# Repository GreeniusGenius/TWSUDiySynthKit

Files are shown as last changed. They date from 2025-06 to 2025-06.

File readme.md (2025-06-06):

# About

- This product is borne out of an original synthesiser kit built by the now bankrupt [Tech Will Save Us](https://en.wikipedia.org/wiki/Technology_Will_Save_Us) company.
- The solderless breadboard nature of it frustrated me, and the lack of room to add a microcontroller for MIDI functionality on the breadboard made it unusable for how I would wish to use it.
- Then I got bored whilst designing it, and decided I'd turn it into a Pi Pico (2(W)) dev board too.
- That way I can prototype all of my projects in a single multipurpose board.
- It supports a Raspberry Pi standard hat.
- It supports a Raspberry Pi Pico bonnet.
- _The second Pi you see in the renderings is actually where two headers will go allowing bonnets to be attached like eInk displays_
- It supports Adafruit Stemma QT and Stemma connectors - which are perfect for prototyping using breakout boards due to the reliable solderless connections.
- It lets me try out the usage of jumpers to bypass voltage dividers reducing potential PCB revisions required due to calculation errors.
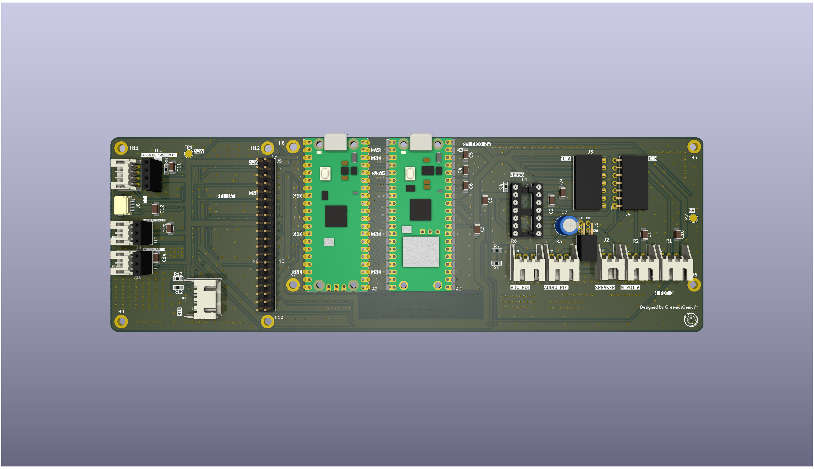
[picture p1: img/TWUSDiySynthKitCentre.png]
Centred Image

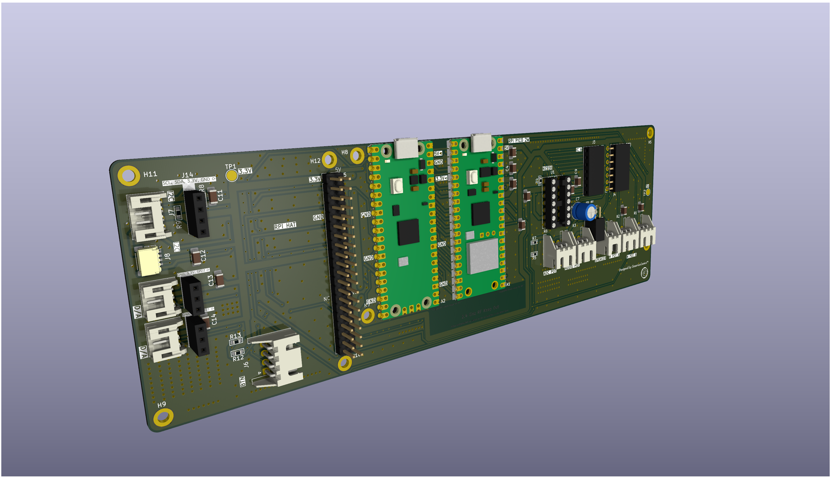
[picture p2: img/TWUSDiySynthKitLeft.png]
Left Hand Image

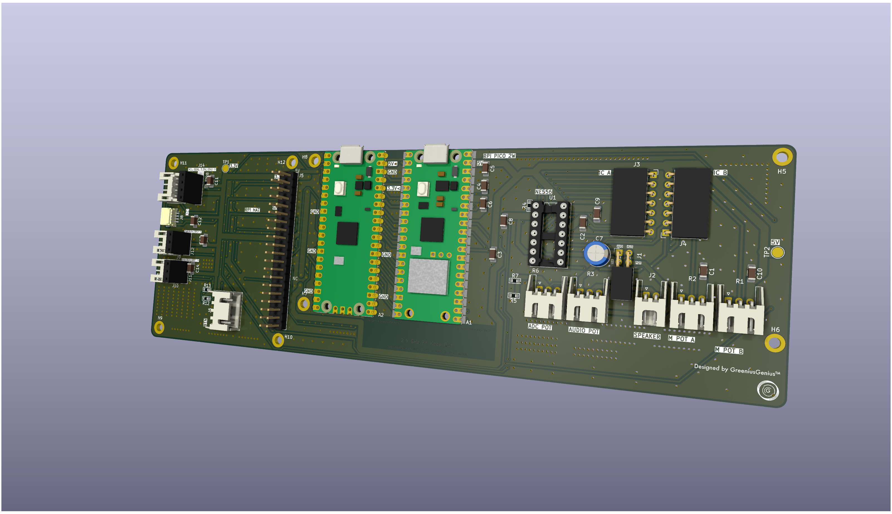
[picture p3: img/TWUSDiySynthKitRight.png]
Right Hand Image

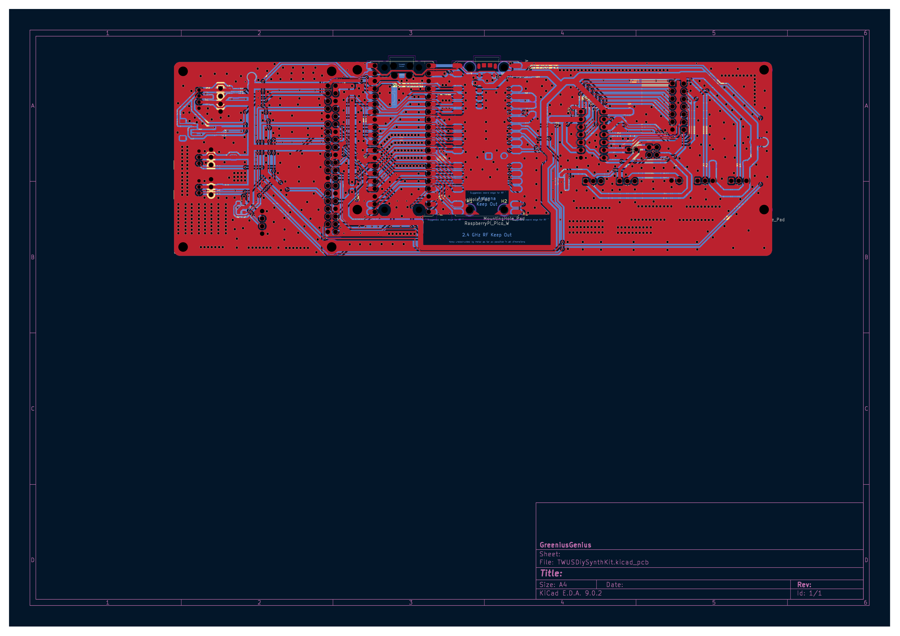
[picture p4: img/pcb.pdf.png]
PCB View

_The PCB is a cost-effective two layer design with ground pours and high density of via stitching reduce ground loops and EMI._
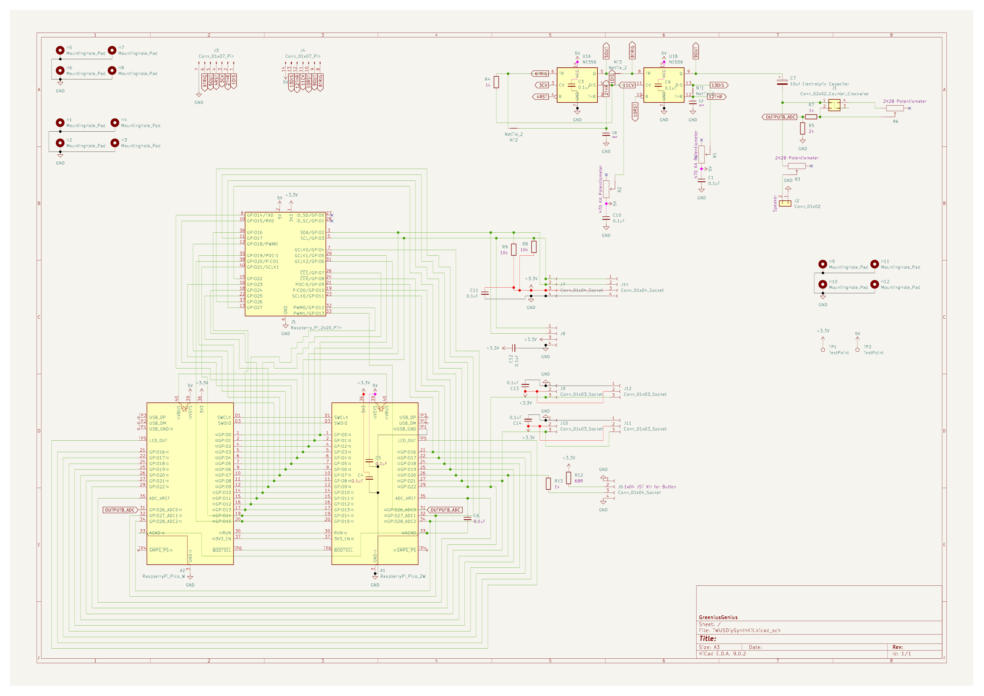
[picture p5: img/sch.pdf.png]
Schematic View

_Plated and grounded mounting holes are used to allow easy multimeter probing and increase durability._
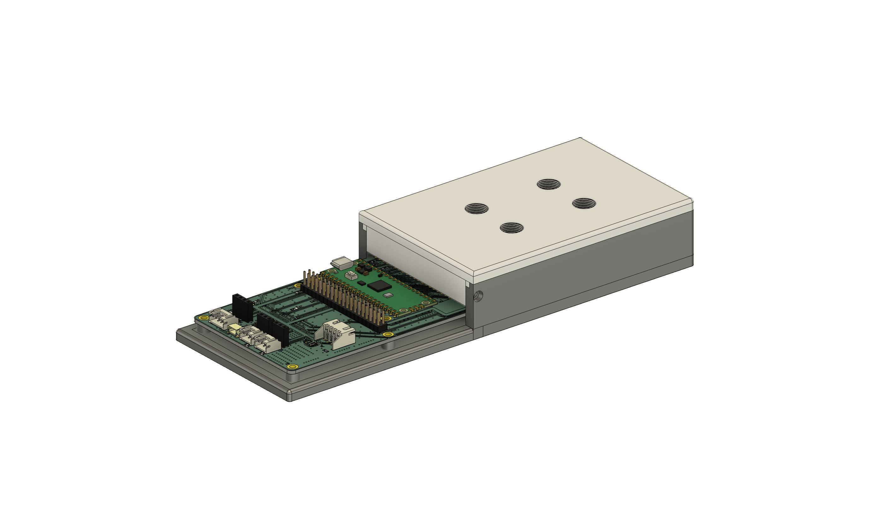
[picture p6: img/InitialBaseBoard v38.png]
Case View

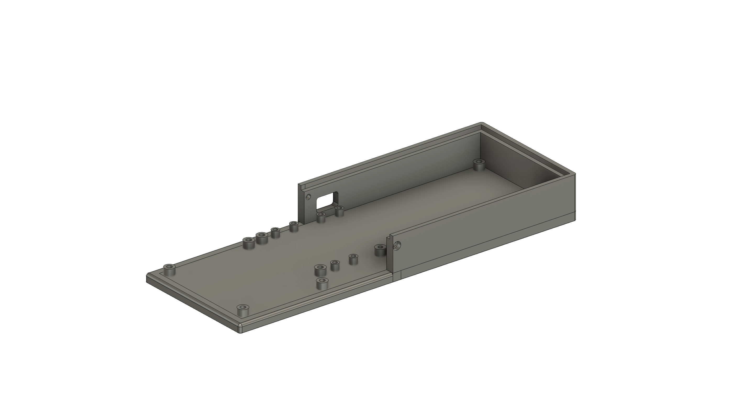
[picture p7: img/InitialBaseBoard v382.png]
Case View No Lid

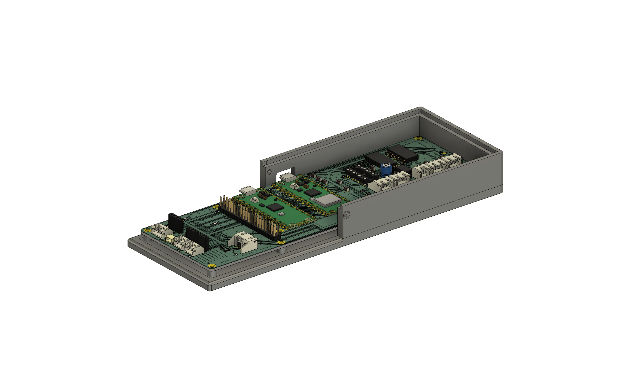
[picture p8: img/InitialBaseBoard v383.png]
Case View No PCB

_The case shields the synthesiser board and Pi Pico (2(W)) whilst the bonnet, hat, and JST connectors for peripherals are easily accessible_

## Bill of Materials
| Reference | Qty | Value | Datasheet | Link / URL | Manufacturer  | Manufacturer_Part_Number | Price (GBP) | GBP/USD | Price (USD) | Justification |
| --- | --- | --- | --- | --- | --- | --- | --- | --- | --- | --- |
| R1, R2 | 2 | 2k 16mm Potentiometer | [https://static.rapidonline.com/pdf/65-1480.pdf](https://static.rapidonline.com/pdf/65-1480.pdf) | https://www.rapidonline.com/omeg-eco2k2lin-2k2-linear-single-16mm-control-pot-65-1401 | Omeg | ECO2K2LIN | £1.75 |  $              1.36 | USD 2.38 | For the volume control and adjustment of the midi volume too |
| R3, R6 | 2 | 470k 16mm potentiometer | [https://static.rapidonline.com/pdf/65-1400e.pdf](https://static.rapidonline.com/pdf/65-1400e.pdf) | https://www.rapidonline.com/omeg-ecoswx470klin-470k-eco-16mm-linear-switched-control-65-1494 | Omeg | ECOSWX470KLIN | £2.57 |  $              1.36 | USD 3.49 | For the input for the synthesizer |
| J6 | 1 | JST XH p2.54mm 4 pin 20cm long wire and connector | [https://www.aliexpress.com/item/1005007460897865.html#nav-specification](https://www.aliexpress.com/item/1005007460897865.html#nav-specification) | [https://www.aliexpress.com/item/1005007460897865.html](https://www.aliexpress.com/item/1005007460897865.html) | Generic | ~ | £0.75 |  $              1.36 | USD 1.02 | Cables for the PCB mount JST connectors to attach accessories |
| J8 | 1 |  JST SH 1.0mm 4 pin 300mm wire and conenctor | https://www.aliexpress.com/item/1005007218127653.html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 | https://www.aliexpress.com/item/1005007218127653.html | Generic | ~ | £0.81 |  $              1.36 | USD 2.21 | |
| J7 | 1 | JST PH 2.0mm 4 pin connector | https://www.aliexpress.com/item/32959854422.html#nav-description | https://www.aliexpress.com/item/32959854422.html | Generic | ~ | £1.63 |  $              1.36 | USD 1.91 | |
| J8 | 2 | JST PH 2.0mm 3 pin connector | https://www.aliexpress.com/item/32959854422.html#nav-description | https://www.aliexpress.com/item/32959854422.html | Generic | ~ | £1.41 |  $              1.36 | USD 1.91 | |
| J2 | 1 | JST XH p2.54mm 2 pin 20cm long wire and connector | [https://www.aliexpress.com/item/1005007460897865.html#nav-specification](https://www.aliexpress.com/item/1005007460897865.html#nav-specification) | [https://www.aliexpress.com/item/1005007460897865.html](https://www.aliexpress.com/item/1005007460897865.html) | Generic | ~ | £0.75 |  $              1.36 | USD 1.02 | |
| J6 | 1 | 16mm 3V LED Button | [https://www.aliexpress.com/item/1005008024309525.html#nav-specification](https://www.aliexpress.com/item/1005008024309525.html#nav-specification) | https://www.aliexpress.com/item/1005008024309525.html | Generic | ~ | £1.26 |  $              1.36 | USD 1.71 | Push to pair bluetooth |
| | | USB-A to Micro-USB cable 0.9m | https://www.amazon.co.uk/dp/B0711PVX6Z?th=1 | https://www.amazon.co.uk/dp/B0711PVX6Z | Amazon Basics | ~ | £3.16 |  $              1.36 | USD 4.29 | Genuinely run out of Micro USB cables - happy to find a cheaper one if necessary as long as it does data |
| PCB | 1 | 5 PCBs (minimum JLCPCB order) | ~ | jlcpcb.com | JLCPCB | ~ | £23.35 |  $              1.36 | USD 31.71 | The PCB |
| | | | | | | | | | | |
| | | | | | | | | | | |
| | | | | | | | | | | |
| | | | | | | Total Price | £37.44 | | USD 51.65 | |
| **Reference** | **Qty** | **Value** | **DNP** | **Exclude from BOM** | **Exclude from Board** | **Footprint** | **Datasheet** | **JLCPCB ID** | **Manufacturer** | **Manufacturer_Part_Number** | **Mouser Part Number** |
| -------------------------------- | ------- | ---------------------------- | ------- | -------------------- | ---------------------- | ---------------------------------------------------------------- | ------------------------------------------------------------------------------------------------------------------------------------------------------------------------------------------------------------------------------------------------------------------------------ | ------------- | ------------------------------------- | ---------------------------- | ---------------------- |
| **R5** | 1 | 2k_0603 | | | | PCM_Resistor_SMD_AKL:R_0603_1608Metric_Pad0.98x0.95mm_HandSolder | [https://www.vishay.com/doc?60018](https://www.vishay.com/doc?60018) | C2076992 | Vishay | M55342E12B2B00RT5 | 75-M55342E12B2B00RT5 |
| **R8,R9** | 2 | 10k_0603 | | | | PCM_Resistor_SMD_AKL:R_0603_1608Metric_Pad0.98x0.95mm_HandSolder | [https://www.vishay.com/doc?28758](https://www.vishay.com/doc?28758) | C2130614 | Vishay | TNPW060310K0FHEA | 71-TNPW060310K0FHEA |
| **R4,R7** | 2 | 1k_0603 | | | | PCM_Resistor_SMD_AKL:R_0603_1608Metric_Pad1.05x0.95mm_HandSolder | [https://www.mouser.co.uk/datasheet/2/385/SEI_RMCF_RMCP-3077565.pdf](https://www.mouser.co.uk/datasheet/2/385/SEI_RMCF_RMCP-3077565.pdf) | C4130738 | SEI Stackpole | RMCF0603JG1K00 | 708-RMCF0603JG1K00 |
| **R13** | 1 | 1k_1210 | | | | PCM_Resistor_SMD_AKL:R_0603_1608Metric_Pad1.05x0.95mm_HandSolder | [https://4donline.ihs.com/images/VipMasterIC/IC/PANA/PANA-S-A0012789169/PANA-S-A0012789169-1.pdf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](https://4donline.ihs.com/images/VipMasterIC/IC/PANA/PANA-S-A0012789169/PANA-S-A0012789169-1.pdf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) | C20024203 | Yageo | ERJ-T14LK102U | 667-ERJ-T14LK102U |
| **C7** | 1 | 10uf Electrolytic Capacitor  | | | | PCM_Capacitor_THT_AKL:CP_Radial_D6.3mm_P2.50mm | [https://industrial.panasonic.com/cdbs/www-data/pdf/RDF0000/ABA0000C1059.pdf](https://industrial.panasonic.com/cdbs/www-data/pdf/RDF0000/ABA0000C1059.pdf) | C1583769 | Panasonic | ECE-A1HKS100B | 667-ECE-A1HKS100B |
| **R12** | 1 | 68R_1210 | | | | PCM_Resistor_SMD_AKL:R_0603_1608Metric_Pad1.05x0.95mm_HandSolder | [https://www.mouser.co.uk/datasheet/2/447/PYu_AC_51_RoHS_L_11-3418659.pdf](https://www.mouser.co.uk/datasheet/2/447/PYu_AC_51_RoHS_L_11-3418659.pdf) | C230487 | Yageo | AC1210JR-0768RL | 603-AC1210JR-0768RL |
| **U1** | 1 | NE556 | | | | Package_DIP:DIP-14_W7.62mm_Socket_LongPads | [http://www.ti.com/lit/ds/symlink/ne556.pdf](http://www.ti.com/lit/ds/symlink/ne556.pdf) | C66175 | Texas Instruments | NE556N | 595-NE556N |
| **A1** | 1 | RaspberryPi_Pico_2W | | | | Module_RaspberryPi_Pico:RaspberryPi_Pico_W_SMD | [https://datasheets.raspberrypi.com/picow/pico-2-w-datasheet.pdf](https://datasheets.raspberrypi.com/picow/pico-2-w-datasheet.pdf) | | Raspberry Pi Foundation | SC1633 | 358-SC1633 |
| **J8** | 1 | Conn_01x04_Socket | | | | Connector_JST:JST_SH_SM04B-SRSS-TB_1x04-1MP_P1.00mm_Horizontal | [https://www.mouser.co.uk/datasheet/2/564/eGH-3477624.pdf](https://www.mouser.co.uk/datasheet/2/564/eGH-3477624.pdf) | C7279904 | Japan Solderless Terminals | SM04B-GHMG-TB-(LF)(SN) | 306-SM04BGHMGTBLFSN |
| **J6** | 1 | Conn_01x04_Socket | | | | Connector_JST:JST_XH_S4B-XH-A-1_1x04_P2.50mm_Horizontal | [https://www.mouser.co.uk/datasheet/2/564/eXH-3476786.pdf](https://www.mouser.co.uk/datasheet/2/564/eXH-3476786.pdf) | C163037 | Japan Solderless Terminals | S4B-XH-A-1(LF)(SN) | 306-S4BXHA1LFSN |
| **R3,R6** | 2 | ECO2K2LIN | | | | Connector_JST:JST_XH_S3B-XH-A-1_1x03_P2.50mm_Horizontal | [https://static.rapidonline.com/pdf/65-1400e.pdf](https://static.rapidonline.com/pdf/65-1400e.pdf), [https://www.mouser.co.uk/datasheet/2/564/eXH-3476786.pdf](https://www.mouser.co.uk/datasheet/2/564/eXH-3476786.pdf) | C163036 | Japan Solderless Terminals | S3B-XH-A-1(LF)(SN) | 306-S3BXHA1LFSN |
| **R1,R2** | 2 | ECOSWX470KLIN | | | | Connector_JST:JST_XH_S3B-XH-A-1_1x03_P2.50mm_Horizontal | [https://static.rapidonline.com/pdf/65-1494.pdf](https://static.rapidonline.com/pdf/65-1494.pdf), [https://www.mouser.co.uk/datasheet/2/564/eXH-3476786.pdf](https://www.mouser.co.uk/datasheet/2/564/eXH-3476786.pdf) | C163036 | Japan Solderless Terminals | S3B-XH-A-1(LF)(SN) | 306-S3BXHA1LFSN |
| **J7** | 1 | Conn_01x04_Socket | | | | Connector_JST:JST_PH_S4B-PH-K_1x04_P2.00mm_Horizontal | [https://www.mouser.co.uk/datasheet/2/564/JST_B4B_PH_SM4_TB_LF_SN_ePH-3481264.pdf](https://www.mouser.co.uk/datasheet/2/564/JST_B4B_PH_SM4_TB_LF_SN_ePH-3481264.pdf) | C157926 | Japan Solderless Terminals | S4B-PH-K-S(LF)(SN) | 306-S4BPHKSLFSN |
| **J9,J10** | 2 | Conn_01x03_Socket | | | | Connector_JST:JST_PH_S3B-PH-K_1x03_P2.00mm_Horizontal | [https://www.mouser.co.uk/datasheet/2/564/JST_B4B_PH_SM4_TB_LF_SN_ePH-3481264.pdf](https://www.mouser.co.uk/datasheet/2/564/JST_B4B_PH_SM4_TB_LF_SN_ePH-3481264.pdf) | C157929 | Japan Solderless Terminals Commercial | S3B-PH-K-S(LF)(SN) | 306-S3BPHKSLFSN |
| **J2** | 1 | Conn_01x02 | | | | Connector_JST:JST_XH_S2B-XH-A-1_1x02_P2.50mm_Horizontal | [https://www.mouser.co.uk/datasheet/2/564/eXH-3476786.pdf](https://www.mouser.co.uk/datasheet/2/564/eXH-3476786.pdf) | C157931 | Japan Solderless Terminals | S2B-XH-A(LF)(SN) | 306-S2B-XH-ALFSN |
| **C4,C5,C6** | 3 | 0.1uF_0603_16V | | | | Capacitor_SMD:C_1206_3216Metric_Pad1.33x1.80mm_HandSolder | [https://www.mouser.co.uk/datasheet/2/585/MLCC-1837944.pdf](https://www.mouser.co.uk/datasheet/2/585/MLCC-1837944.pdf) | C6766062 | Samsung Electro-Mechanics | CL31B104KBCNNND | 187-CL31B104KBCNNND |
| **C1,C3,C9,C10,C11,C12,C13,C14** | 8 | 0.1uF | | | | Capacitor_SMD:C_1206_3216Metric_Pad1.33x1.80mm_HandSolder | [https://www.mouser.co.uk/datasheet/2/585/MLCC-1837944.pdf](https://www.mouser.co.uk/datasheet/2/585/MLCC-1837944.pdf) | C6766062 | Samsung Electro-Mechanics | CL31B104KBCNNND | 187-CL31B104KBCNNND |
| **C2,C8** | 2 | 10nF_0603_25V | | | | Capacitor_SMD:C_1206_3216Metric_Pad1.33x1.80mm_HandSolder | [https://www.mouser.co.uk/datasheet/2/585/MLCC-1837944.pdf](https://www.mouser.co.uk/datasheet/2/585/MLCC-1837944.pdf) | C16196152 | Samsung Electro-Mechanics | CL31B103KHFNFNE | 187-CL31B103KHFNFNE |
| **TP1,TP2** | 2 | TestPoint | | | | TestPoint:TestPoint_Pad_D2.5mm | ~ | | | | |
| **NT1,NT2,NT3** | 3 | NetTie_2 | | Excluded from BOM | | NetTie:NetTie-2_SMD_Pad0.5mm | ~ | | | | |
| **J14** | 1 | Conn_01x04_Socket | | | | Connector_PinSocket_2.54mm:PinSocket_1x04_P2.54mm_Vertical | ~ | | | | |
| **J11,J12** | 2 | Conn_01x03_Socket | | | | Connector_PinSocket_2.54mm:PinSocket_1x03_P2.54mm_Vertical | ~ | | | | |
| **J5** | 1 | Raspberry_Pi_2x20_PTH | | | | Connector_PinHeader_2.54mm:PinHeader_2x20_P2.54mm_Vertical | [https://www.raspberrypi.org/documentation/hardware/raspberrypi/schematics/rpi_SCH_3bplus_1p0_reduced.pdf](https://www.raspberrypi.org/documentation/hardware/raspberrypi/schematics/rpi_SCH_3bplus_1p0_reduced.pdf) | | | | |
| **J3,J4** | 2 | Conn_01x07_Pin | | | | Connector_PinSocket_2.54mm:PinSocket_1x07_P2.54mm_Horizontal | ~ | | | | |
| **J1** | 1 | Conn_02x02_Counter_Clockwise | | | | Connector_PinSocket_2.54mm:PinSocket_2x02_P2.54mm_Horizontal | ~ | | | | |
| **H5,H6,H7,H8,H9,H10,H11,H12** | 8 | MountingHole_Pad | | Excluded from BOM | | MountingHole:MountingHole_2.7mm_M2.5_DIN965_Pad | ~ | | | | |
| **H1,H2,H3,H4** | 4 | MountingHole_Pad | | Excluded from BOM | | MountingHole:MountingHole_2.2mm_M2_DIN965 | ~ | | | | |
| **A2** | 1 | RaspberryPi_Pico_W | | Excluded from BOM | | Module_RaspberryPi_Pico:RaspberryPi_Pico_Common_MountingHoles | [https://datasheets.raspberrypi.com/picow/pico-w-datasheet.pdf](https://datasheets.raspberrypi.com/picow/pico-w-datasheet.pdf) | | | | |

| FileName | Quantity | Price  |
|---|---|---|
| InitialBaseBoard Base.step | 1 | $17.16 |
| InitialBaseBoard Lid.step  | 1 | $7.78  |

Notes: The .csv file contains the PCB mounted bill of materials.
The ExtraBOM contains the wiring needed to connect etc.
The link to the mouser basket is here: https://www.mouser.co.uk/ProjectManager/ProjectDetail.aspx?AccessID=711d47ef2e

Mouser components + shipping to United Kingdom is £24.41 or US$33.12

Components in .xlsx are £43.17 or US$59.46

3D Printed Casing is about US$24.94 (£18.41) + at least US$16.10 (£11.88) shipping from PCBWay for a total of £30.29 and US$41.04

**Therefore the total cost is £97.87 and US$133.62.**

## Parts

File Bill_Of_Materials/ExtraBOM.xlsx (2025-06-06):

Reference | Qty | Value | Datasheet | Link / URL | Manufacturer | Manufacturer_Part_Number | Unit Price (GBP) | #VALUE! | Unit Price (USD) | Quantity Price (GBP) | Quantity Price (USD) | Justification
R1, R2 | 2 | 2k 16mm Potentiometer | https://static.rapidonline.com/pdf/65-1480.pdf | https://www.rapidonline.com/omeg-eco2k2lin-2k2-linear-single-16mm-control-pot-65-1401 | Omeg | ECO2K2LIN | £1.75 | $1.36 | USD 2.38 | £3.50 | USD 4.75 | For the volume control and adjustment of the midi volume too
R3, R6 | 2 | 470k 16mm potentiometer | https://static.rapidonline.com/pdf/65-1400e.pdf | https://www.rapidonline.com/omeg-ecoswx470klin-470k-eco-16mm-linear-switched-control-65-1494 | Omeg | ECOSWX470KLIN | £2.57 | $1.36 | USD 3.49 | £5.14 | USD 6.98 | For the input for the synthesizer
J6 | 1 | JST XH p2.54mm 4 pin 20cm long wire and connector | https://www.aliexpress.com/item/1005007460897865.html#nav-specification | https://www.aliexpress.com/item/1005007460897865.html | Generic | ~ | £0.75 | $1.36 | USD 1.02 | £0.75 | USD 1.02 | Cables for the PCB mount JST connectors to attach accessories
J8 | 1 | JST SH 1.0mm 4 pin 300mm wire and conenctor | https://www.aliexpress.com/item/1005007218127653.html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 | https://www.aliexpress.com/item/1005007218127653.html | Generic | ~ | £0.81 | $1.36 | USD 2.21 | £0.81 | USD 2.21
J7 | 1 | JST PH 2.0mm 4 pin connector | https://www.aliexpress.com/item/32959854422.html#nav-description | https://www.aliexpress.com/item/32959854422.html | Generic | ~ | £1.63 | $1.36 | USD 1.92 | £1.63 | USD 1.92
J8 | 2 | JST PH 2.0mm 3 pin connector | https://www.aliexpress.com/item/32959854422.html#nav-description | https://www.aliexpress.com/item/32959854422.html | Generic | ~ | £1.41 | $1.36 | USD 1.92 | £2.82 | USD 3.83
J2 | 1 | JST XH p2.54mm 2 pin 20cm long wire and connector | https://www.aliexpress.com/item/1005007460897865.html#nav-specification | https://www.aliexpress.com/item/1005007460897865.html | Generic | ~ | £0.75 | $1.36 | USD 1.02 | £0.75 | USD 1.02
J6 | 1 | 16mm 3V LED Button | https://www.aliexpress.com/item/1005008024309525.html#nav-specification | https://www.aliexpress.com/item/1005008024309525.html | Generic | ~ | £1.26 | $1.36 | USD 1.71 | £1.26 | USD 1.71 | Push to pair bluetooth
USB | 1 | USB-A to Micro-USB cable 0.9m | https://www.amazon.co.uk/dp/B0711PVX6Z?th=1 | https://www.amazon.co.uk/dp/B0711PVX6Z | Amazon Basics | ~ | £3.16 | $1.36 | USD 4.29 | £3.16 | USD 4.29 | Genuinely run out of Micro USB cables - happy to find a cheaper one if necessary as long as it does data
PCB | 1 | 5 PCBs (minimum JLCPCB order) | ~ | jlcpcb.com | JLCPCB | ~ | £23.35 | $1.36 | USD 31.72 | £23.35 | USD 31.72 | The PCB
 |  |  |  |  |  |  |  |  |  | GBP | USD
 |  |  |  |  |  |  |  |  | Total | £43.17 | USD 59.46

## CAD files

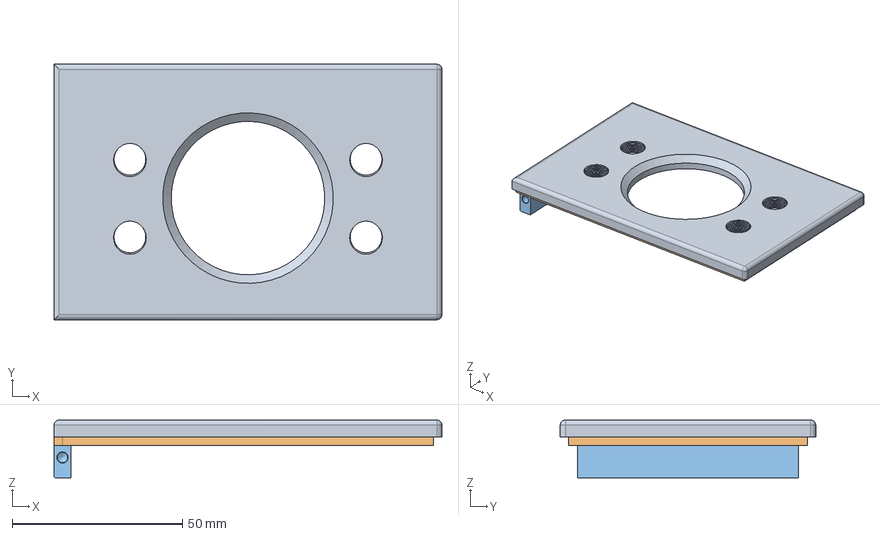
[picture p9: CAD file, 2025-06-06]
cad/InitialBaseBoard Lid.step
113.8 x 75.0 x 17.0 mm
LidTop
LidKey
LidSideWall

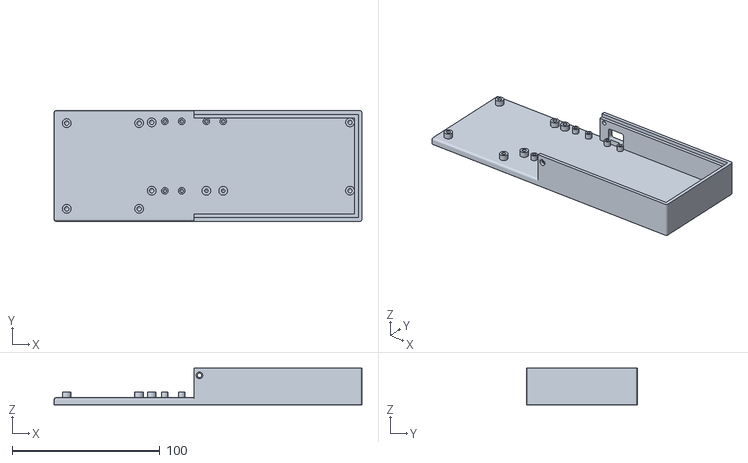
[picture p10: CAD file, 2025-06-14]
cad/sat14jun/InitialBaseBoard v63 Base.stl
208.4 x 75.0 x 25.0

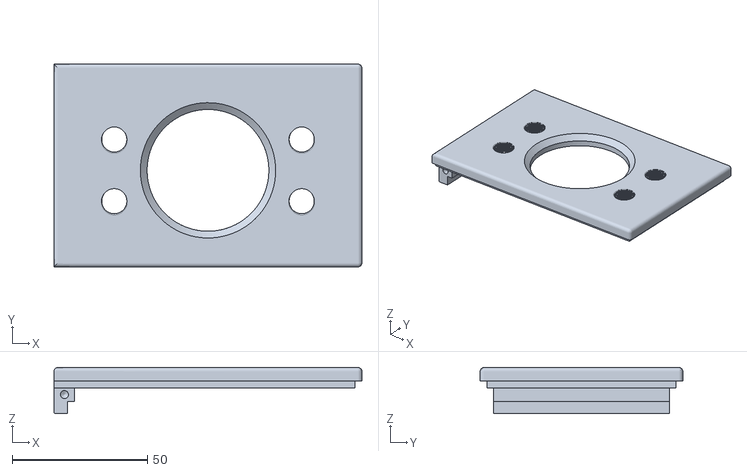
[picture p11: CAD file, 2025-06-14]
cad/sat14jun/InitialBaseBoard v63 Lid.stl
113.8 x 75.0 x 17.0

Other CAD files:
cad/InitialBaseBoard Base.step
cad/InitialBaseBoard Base.stl
cad/InitialBaseBoard Lid.stl

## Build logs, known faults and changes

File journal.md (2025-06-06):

# Journal
 - Oldest at top, newest at bottom of text file.

## Thu 5 Jun 2025
I'd love to say I knew how long I spent on the project so far.
The answer is I don't know.
Probably at least 6 hours, beginning on 31st of May 2025.
I took some inspiration from [baklokb/pcb-pico-pi-base](https://github.com/bablokb/pcb-pico-pi-base)
This allowed me to connect the Pico with standard Pi hats.
PCB View
_By now the PCB was pretty much complete_

## Fri 6 Jun 2025
Spent a few hours working on CAD for the casing:
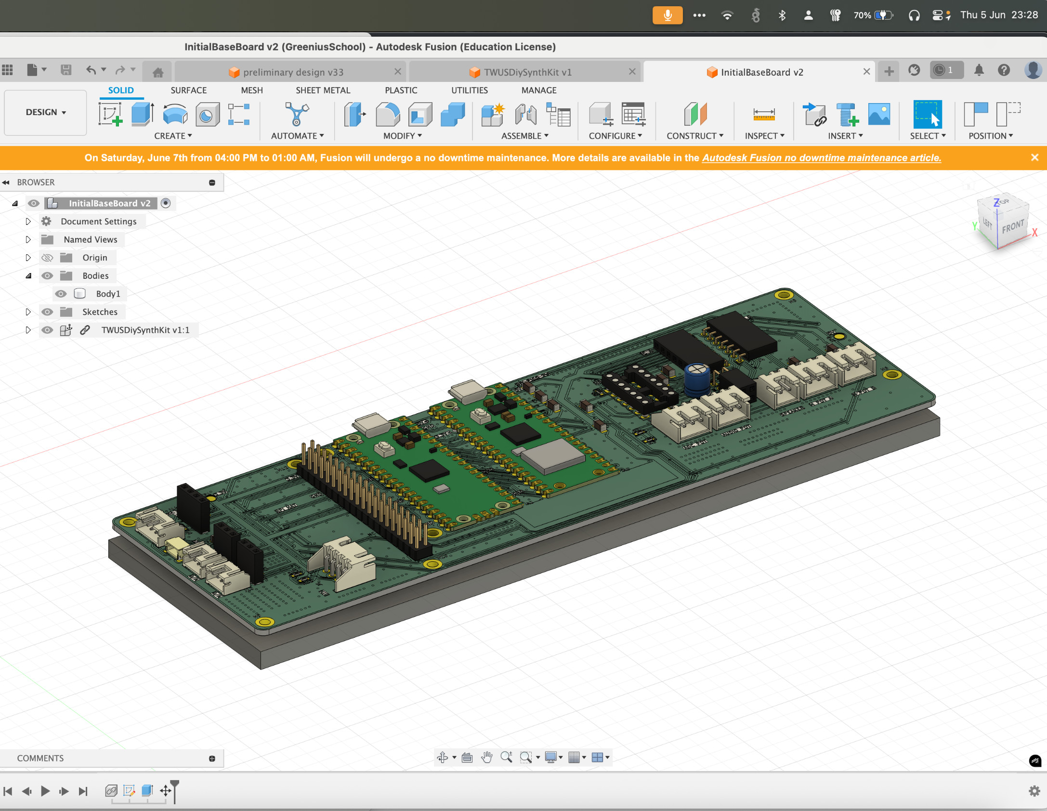
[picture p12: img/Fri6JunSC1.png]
Base Plate

_Started with a base plate_

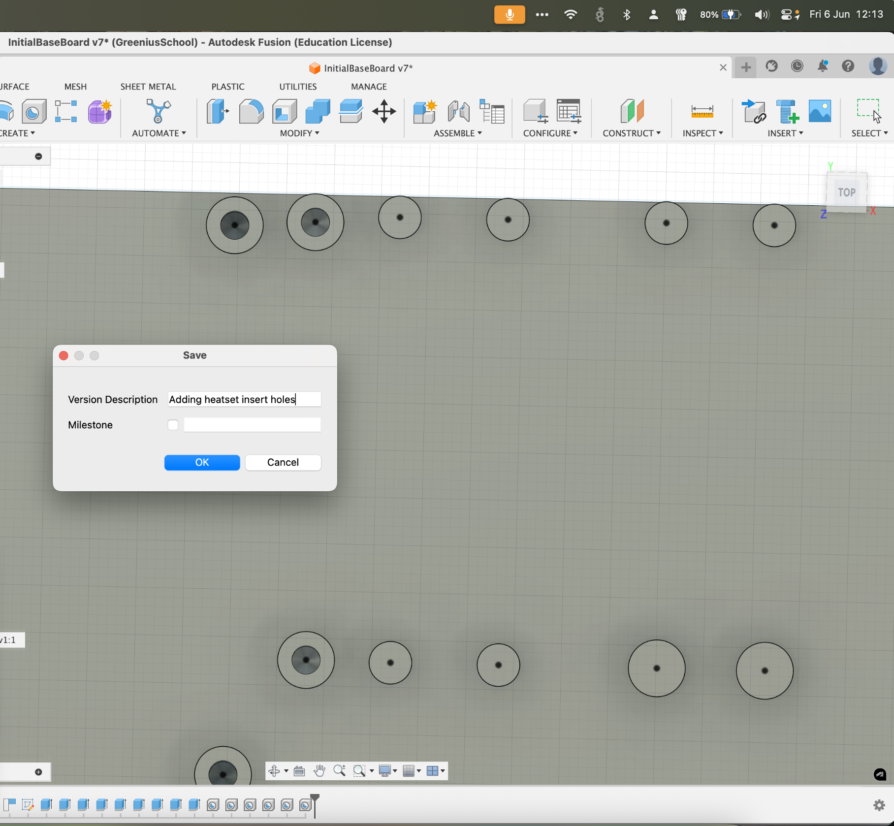
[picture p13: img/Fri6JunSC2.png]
Standoffs

_Then added standoff pillars and room for heatset inserts as appropriate to support the PCB and allow clearance for the throughhole components._

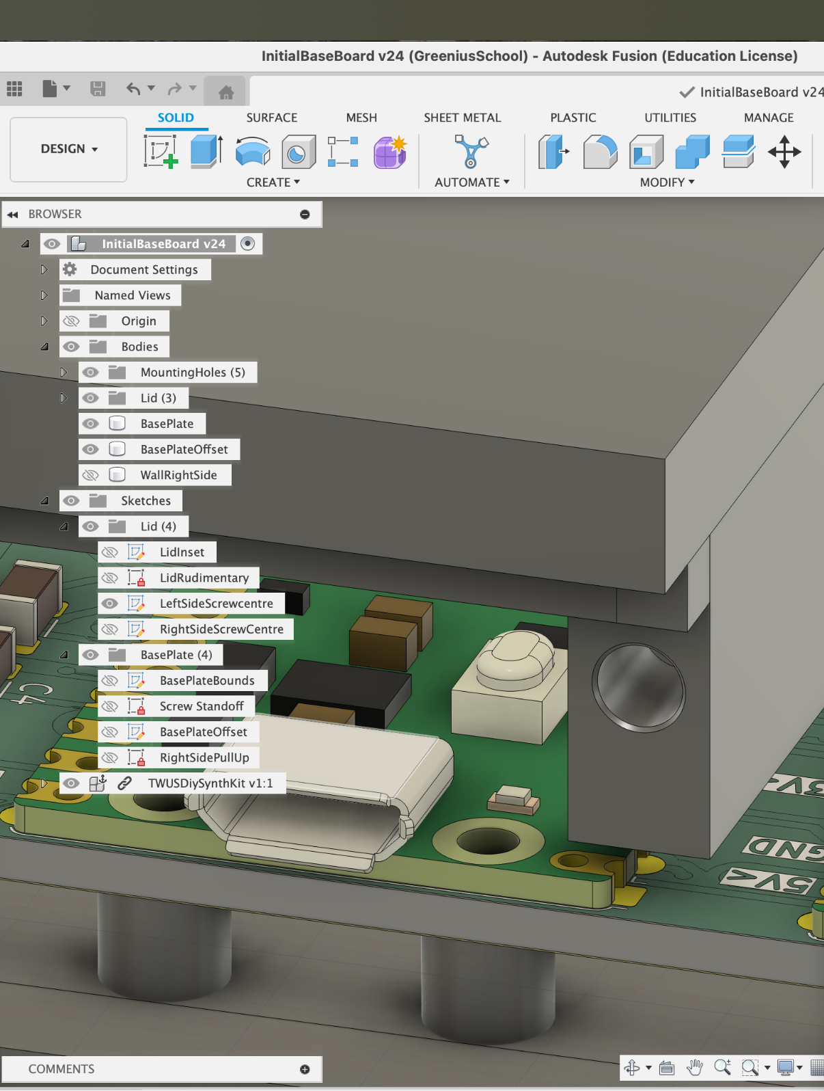
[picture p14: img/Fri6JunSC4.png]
Lid Screws

_Then I added a way to secure the lid to the casing. I tapered to allow the heatset inserts to be inserted with relative ease, and added counterbores in the external walls for the screw to sit flush._

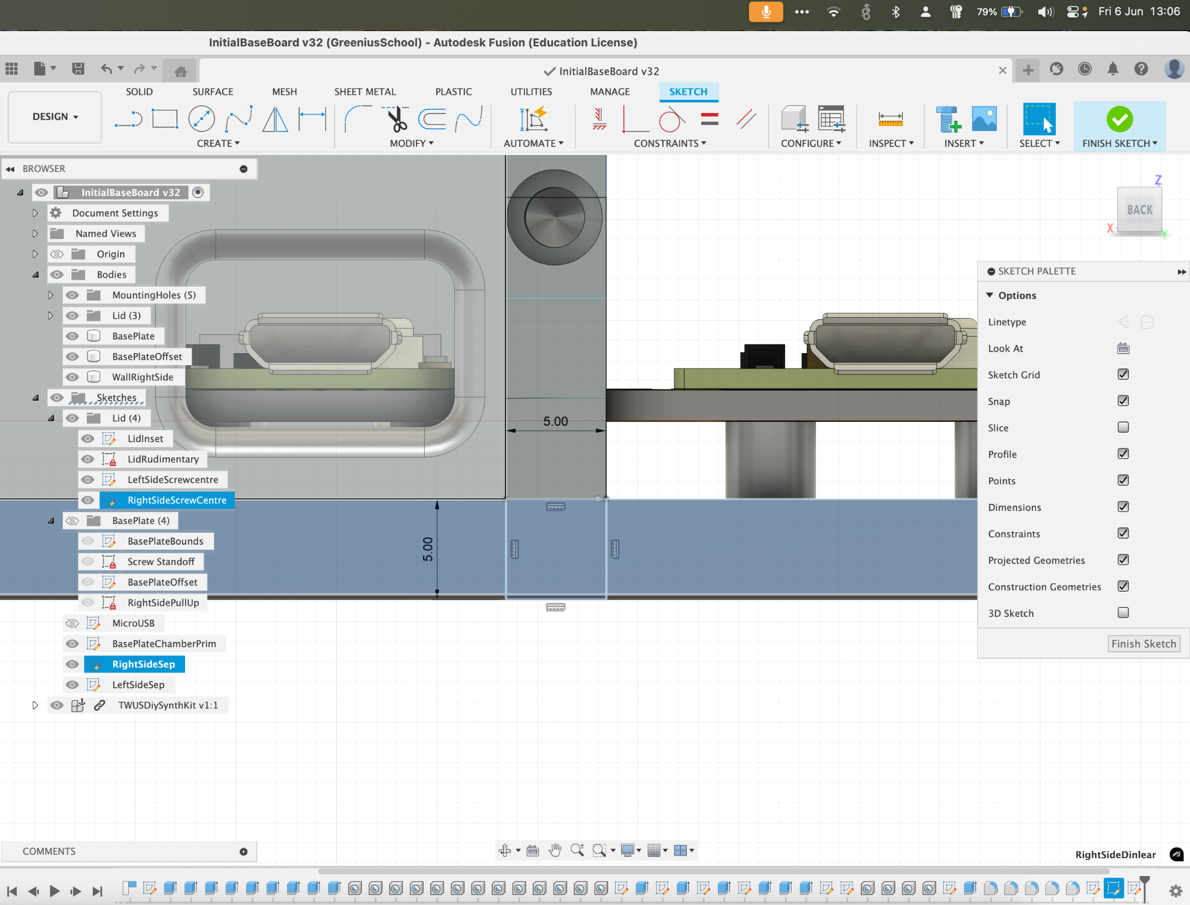
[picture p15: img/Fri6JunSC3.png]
Port Access

_Then I added a way to plug in the Micro USB port to the casing of the Raspberry Pi.
_
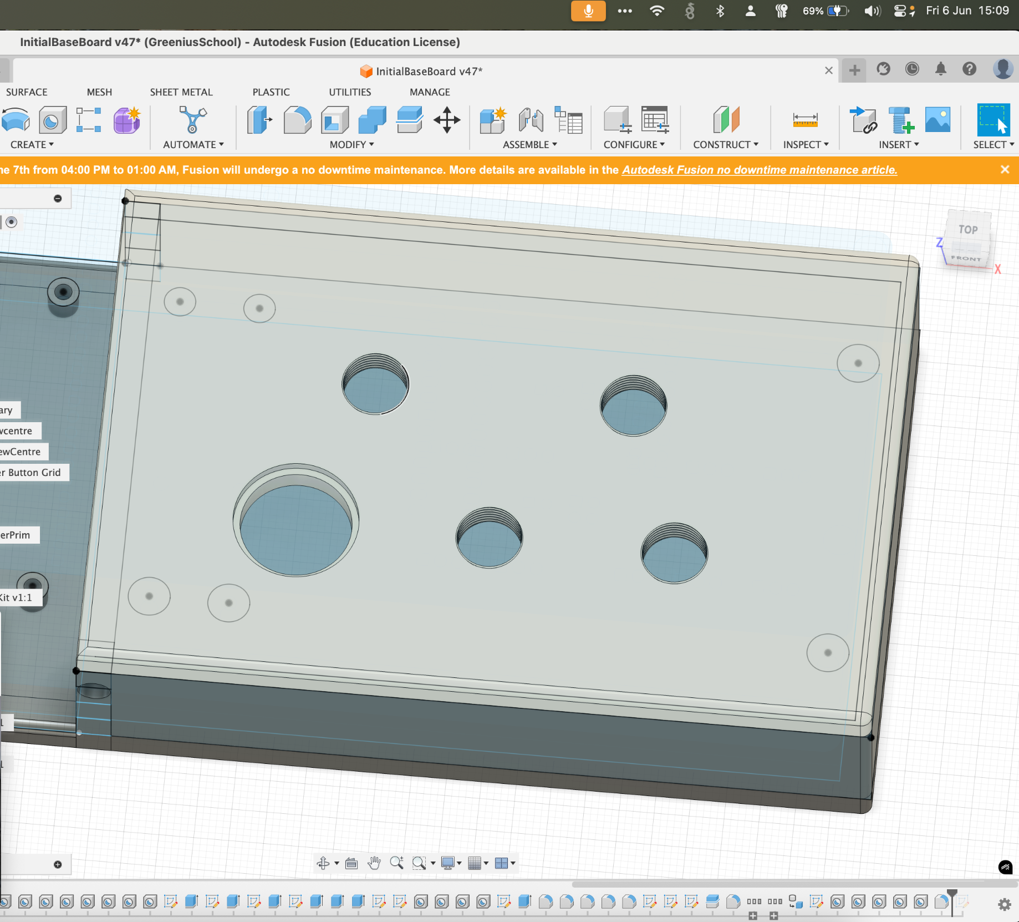
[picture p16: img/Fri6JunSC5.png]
Mounting for Potentiometers

_Then I added a way to screw in my potentiometers since they have an M10 threading._

At least another 3 hours.

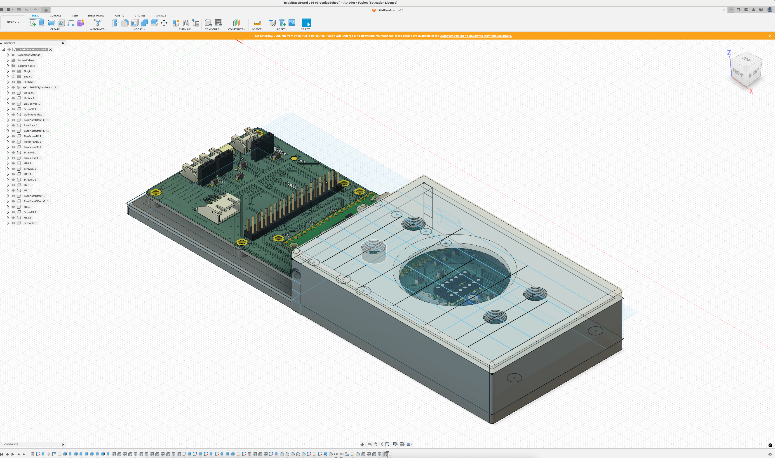
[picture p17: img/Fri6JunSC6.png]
Mounting for Speaker Driver

_Added Speaker Aperture with bevelled edge so it is hypothetically flush_
Another 15 mins.

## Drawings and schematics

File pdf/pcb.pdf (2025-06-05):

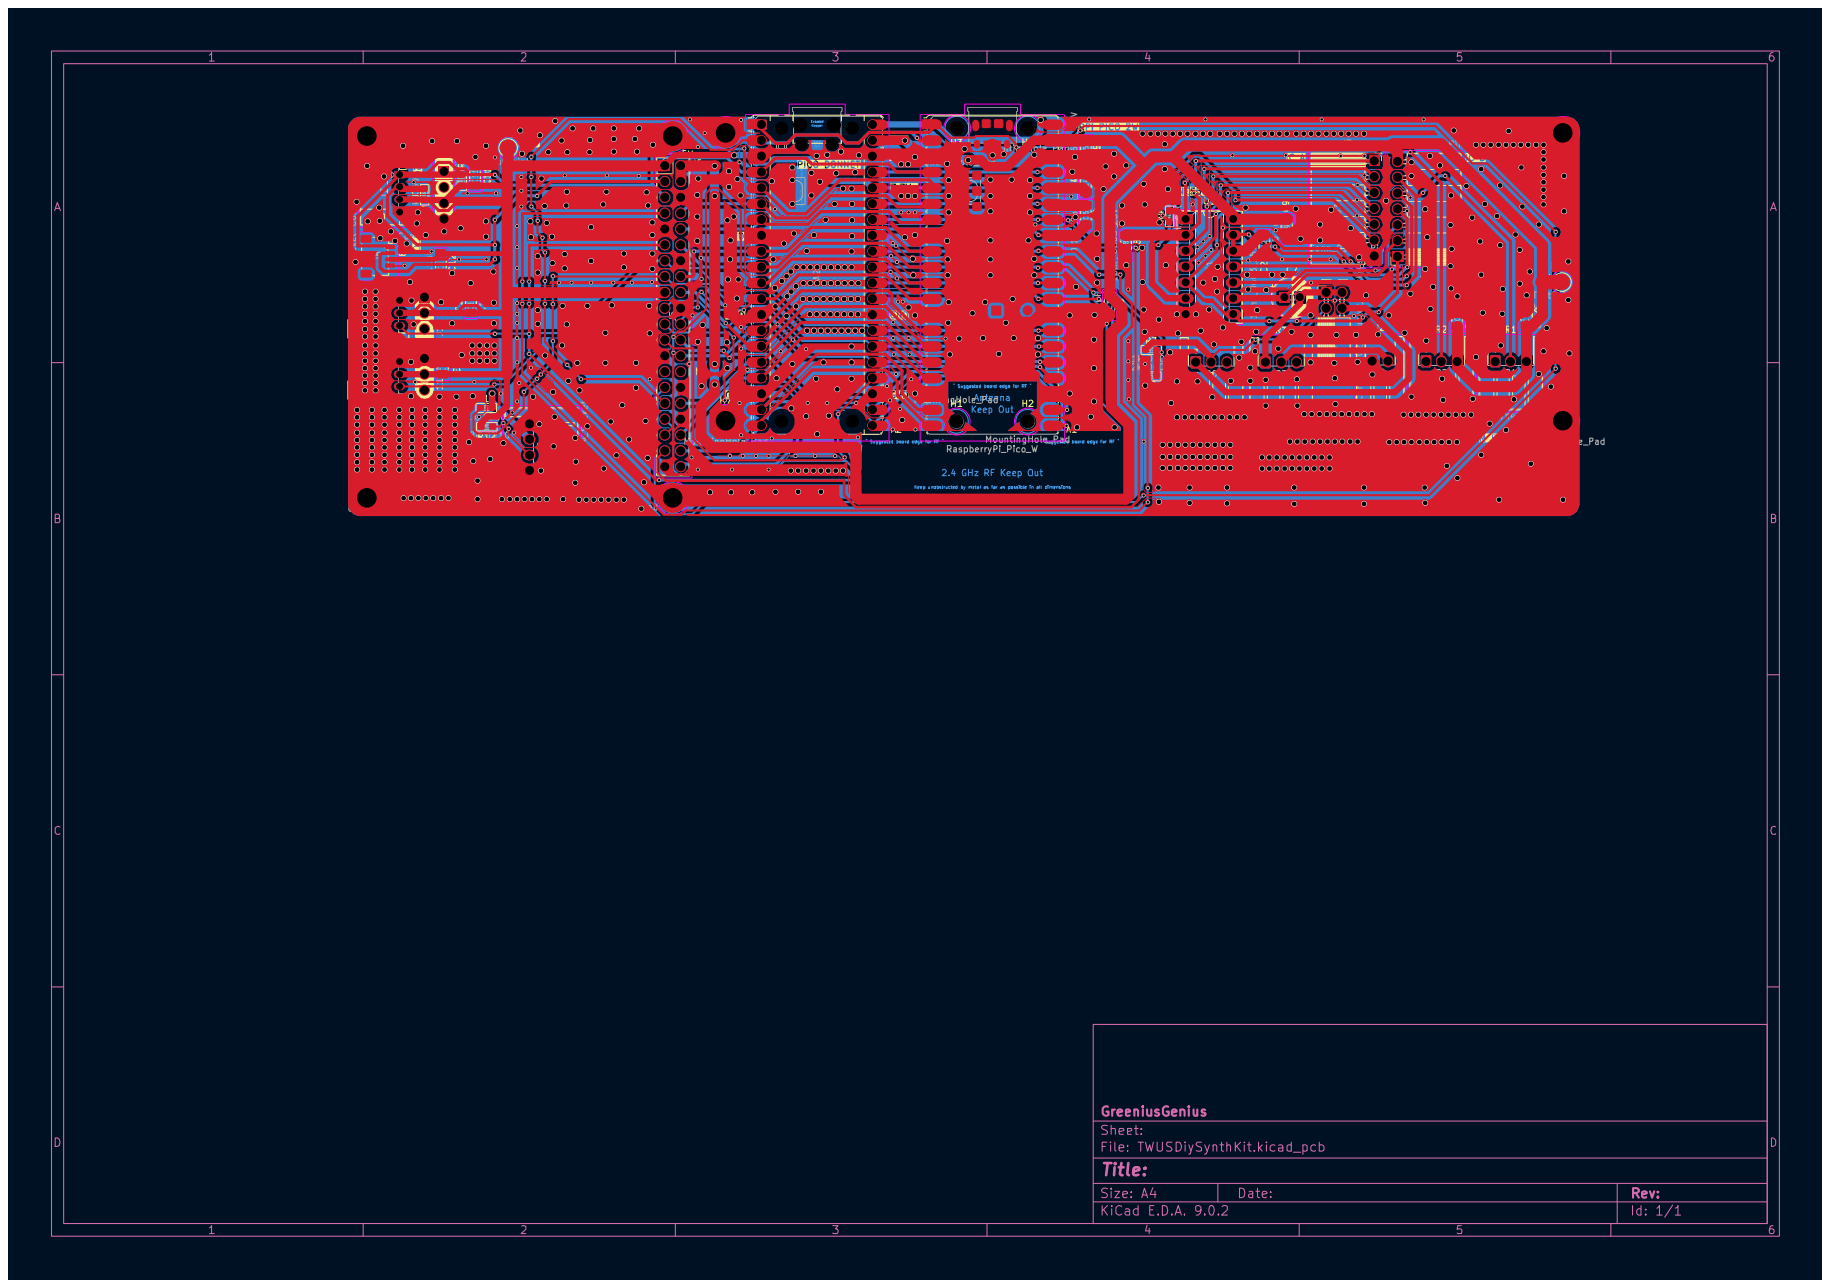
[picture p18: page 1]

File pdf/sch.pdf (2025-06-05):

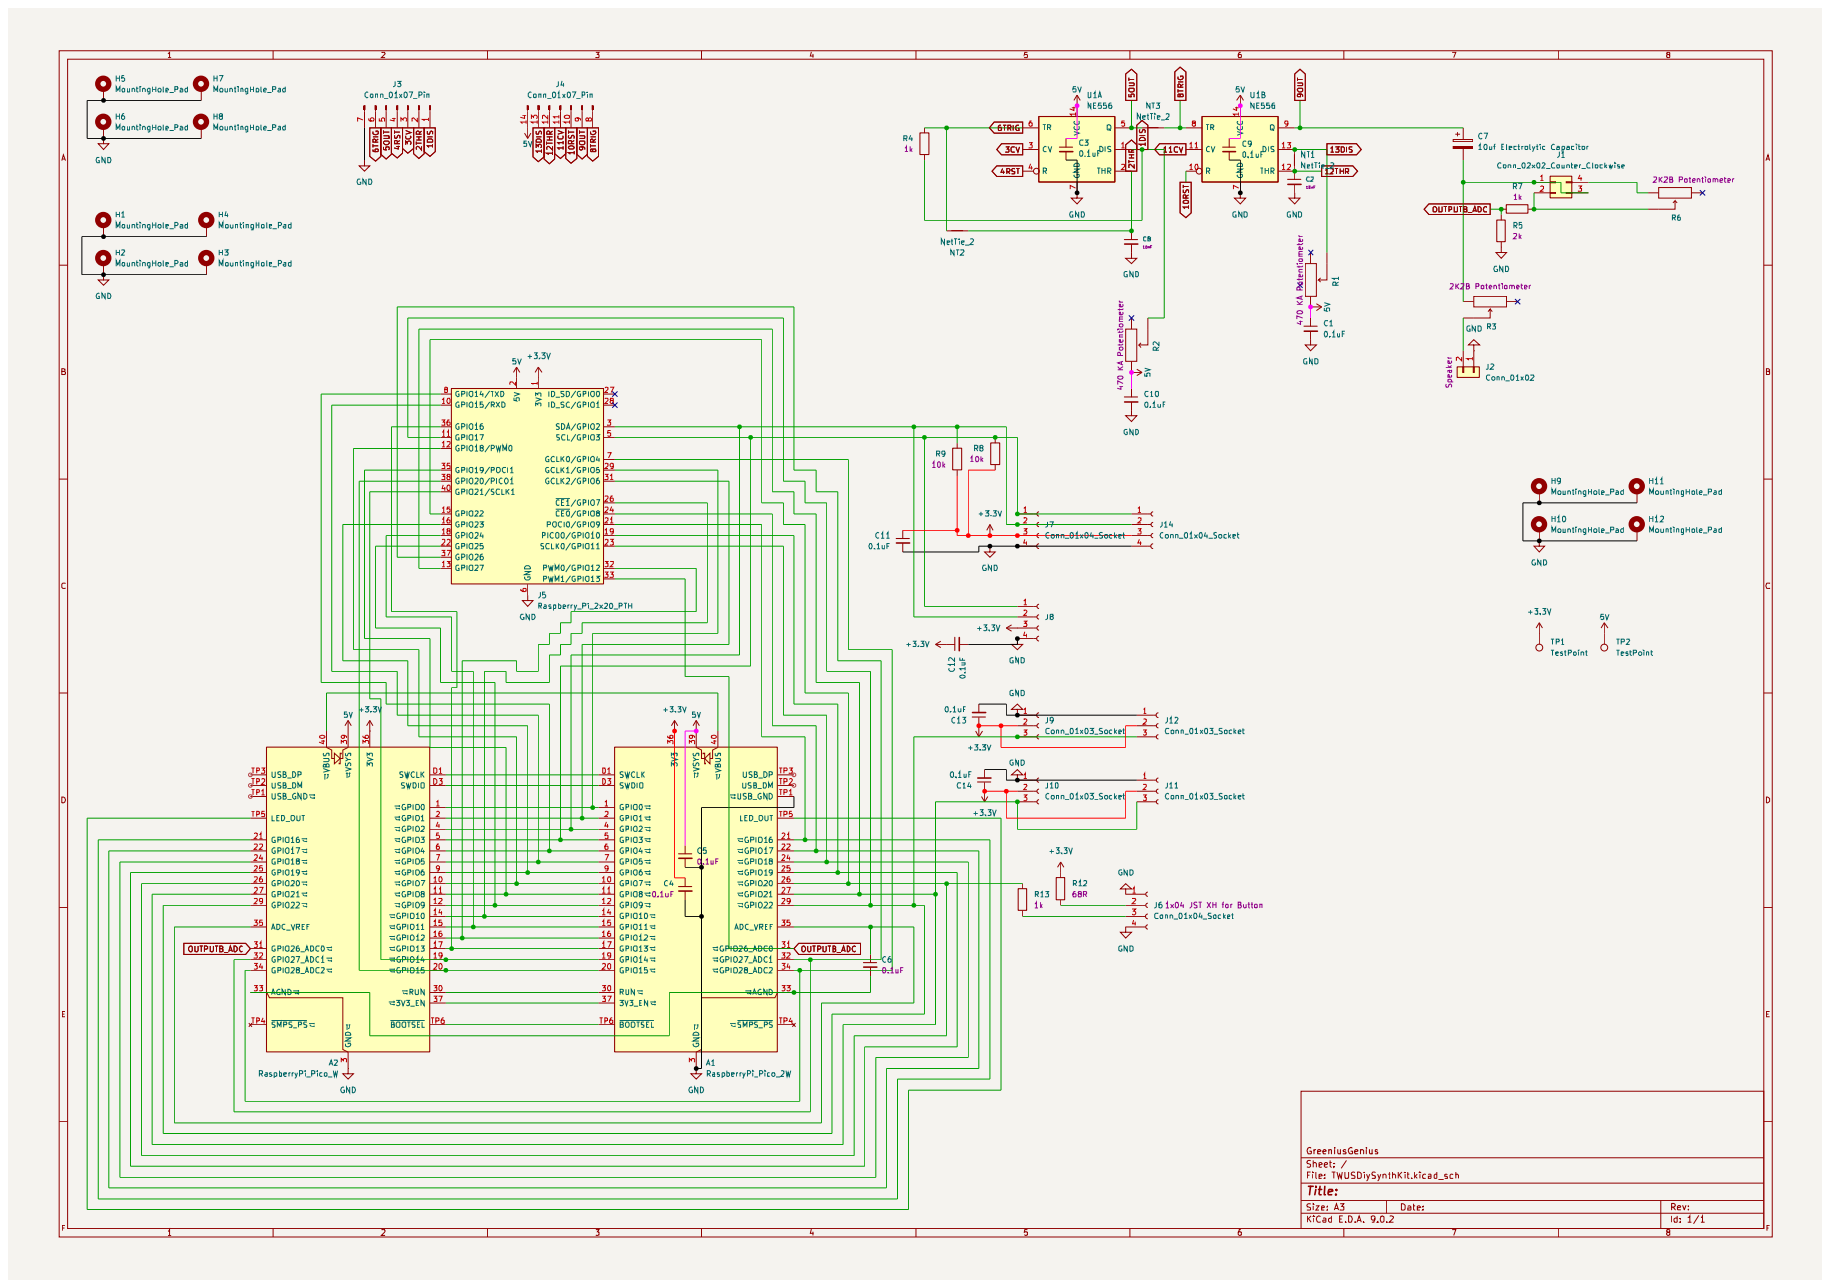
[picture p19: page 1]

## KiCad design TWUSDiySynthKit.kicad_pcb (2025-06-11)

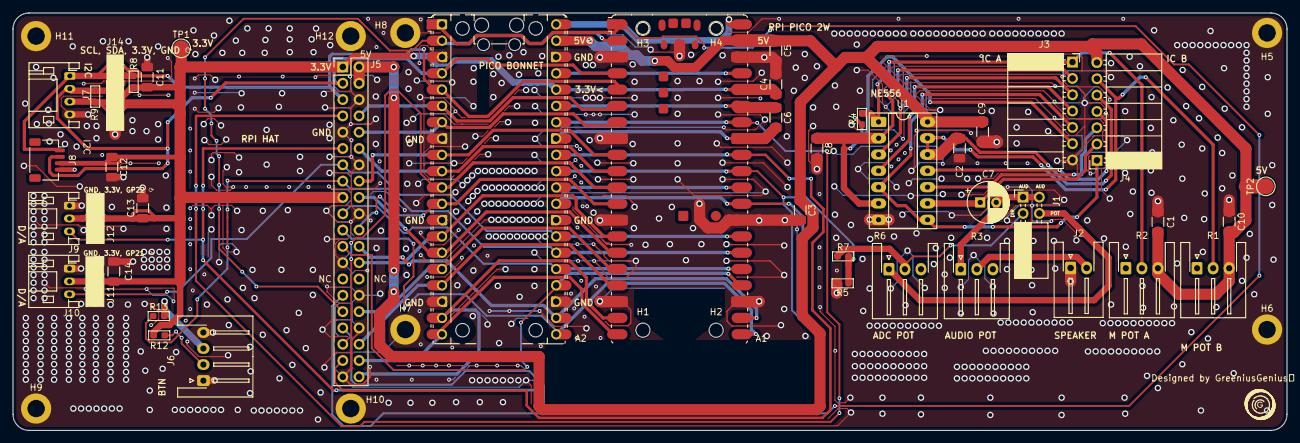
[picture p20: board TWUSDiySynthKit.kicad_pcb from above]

Board: 2 copper layers, 198.4 x 65.0 mm, 58 parts (0 on the bottom side), 52 nets.

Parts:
A1: RaspberryPi_Pico_W; RaspberryPi_Pico_W_SMD
A2: RaspberryPi_Pico_W; RaspberryPi_Pico_Common_MountingHoles
C1, C3, C9, C10, C11, C12, C13, C14: 0.1uF; C_1206_3216Metric_Pad1.33x1.80mm_HandSolder
C2, C8: 10nF_0603_25V; C_1206_3216Metric_Pad1.33x1.80mm_HandSolder
C4, C5, C6: 0.1uF_0603_16V; C_1206_3216Metric_Pad1.33x1.80mm_HandSolder
C7: 10uf Electrolytic Capacitor; CP_Radial_D6.3mm_P2.50mm
H1, H2, H3, H4: MountingHole_Pad; MountingHole_2.2mm_M2_DIN965
H5, H6, H7, H8, H9, H10, H11, H12: MountingHole_Pad; MountingHole_2.7mm_M2.5_DIN965_Pad
J1: Conn_02x02_Counter_Clockwise; PinSocket_2x02_P2.54mm_Horizontal
J2: Conn_01x02; JST_XH_S2B-XH-A-1_1x02_P2.50mm_Horizontal
J3, J4: Conn_01x07_Pin; PinSocket_1x07_P2.54mm_Horizontal
J5: Raspberry_Pi_2x20_PTH; PinHeader_2x20_P2.54mm_Vertical
J6: Conn_01x04_Socket; JST_XH_S4B-XH-A-1_1x04_P2.50mm_Horizontal
J7: Conn_01x04_Socket; JST_PH_S4B-PH-K_1x04_P2.00mm_Horizontal
J8: Conn_01x04_Socket; JST_SH_SM04B-SRSS-TB_1x04-1MP_P1.00mm_Horizontal
J9, J10: Conn_01x03_Socket; JST_PH_S3B-PH-K_1x03_P2.00mm_Horizontal
J11, J12: Conn_01x03_Socket; PinSocket_1x03_P2.54mm_Vertical
J14: Conn_01x04_Socket; PinSocket_1x04_P2.54mm_Vertical
NT1, NT2, NT3: NetTie_2; NetTie-2_SMD_Pad0.5mm
R1, R2: ECOSWX470KLIN; JST_XH_S3B-XH-A-1_1x03_P2.50mm_Horizontal
R3, R6: ECO2K2LIN; JST_XH_S3B-XH-A-1_1x03_P2.50mm_Horizontal
R4, R7: 1k_0603; R_0603_1608Metric_Pad1.05x0.95mm_HandSolder
R5: 2k_0603; R_0603_1608Metric_Pad0.98x0.95mm_HandSolder
R8, R9: 10k_0603; R_0603_1608Metric_Pad0.98x0.95mm_HandSolder
R12: 68R_1210; R_0603_1608Metric_Pad1.05x0.95mm_HandSolder
R13: 1k_1210; R_0603_1608Metric_Pad1.05x0.95mm_HandSolder
TP1, TP2: TestPoint; TestPoint_Pad_D2.5mm
U1: NE556; DIP-14_W7.62mm_Socket_LongPads

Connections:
1DIS: J3.1, R2.2 (Wiper), R4.2, U1.1 (DIS)
2THR: C8.1, J3.2, NT2.1, U1.2 (THR)
3CV: J3.3, U1.3 (CV)
4RST: J3.4, U1.4 (R)
5OUT: J3.5, NT3.1, U1.5 (Q)
5V: A1.39 (VSYS), A2.39 (VSYS), C1.1, C3.1, C5.1, C9.1, C10.1, J4.14, J5.2 (5V), J5.4 (5V), R1.3, R2.3, TP2.1, U1.14 (VCC)
6TRIG: J3.6, NT2.2, R4.1, U1.6 (TR)
8TRIG: J4.8, NT3.2, U1.8 (TR)
9OUT: C7.1, J4.9, U1.9 (Q)
10RST: J4.10, U1.10 (R)
11CV: J4.11, U1.11 (CV)
12THR: C2.1, J4.12, NT1.1, U1.12 (THR)
13DIS: J4.13, NT1.2, R1.2 (Wiper), U1.13 (DIS)
+3.3V: A1.36 (3V3), A2.36 (3V3), C4.1, C11.1, C12.1, C13.1, C14.1, J5.1 (3V3), J5.17 (3V3), J7.3, J8.3, J9.2, J10.2, J11.2, J12.2, J14.3, R8.2, R9.2, R12.1, TP1.1
GND: A1.3 (GND), A1.8 (GND), A1.13 (GND), A1.18 (GND), A1.23 (GND), A1.28 (GND), A1.38 (GND), A1.D2 (GND), A1.TP1 (USB_GND), A2.3 (GND), A2.8 (GND), A2.13 (GND), A2.18 (GND), A2.23 (GND), A2.28 (GND), A2.38 (GND), C1.2, C2.2, C3.2, C4.2, C5.2, C8.2, C9.2, C10.2, C11.2, C12.2, C13.2, C14.2, H5.1, H6.1, H7.1, H8.1, H9.1, H10.1, H11.1, H12.1, J2.1, J3.7, J5.6 (GND), J5.9 (GND), J5.14 (GND), J5.20 (GND), J5.25 (GND), J5.30 (GND), J5.34 (GND), J5.39 (GND), J6.1, J6.4, J7.4, J8.4, J9.1, J10.1, J11.1, J12.1, J14.4, R5.2, U1.7 (GND)
unnamed: A1.37 (3V3_EN), A2.37 (3V3_EN)
unnamed: A1.35 (ADC_VREF), A2.35 (ADC_VREF), C6.1
unnamed: A1.33 (AGND), A2.33 (AGND), C6.2
unnamed: A1.1 (GPIO0), A2.1 (GPIO0), J5.29 (GCLK1/GPIO5)
unnamed: A1.2 (GPIO1), A2.2 (GPIO1), J5.31 (GCLK2/GPIO6)
unnamed: A1.4 (GPIO2), A2.4 (GPIO2), J5.3 (SDA/GPIO2), J7.2, J8.2, J14.2, R9.1
unnamed: A1.5 (GPIO3), A2.5 (GPIO3), J5.5 (SCL/GPIO3), J7.1, J8.1, J14.1, R8.1
unnamed: A1.6 (GPIO4), A2.6 (GPIO4), J5.8 (GPIO14/TXD)
unnamed: A1.7 (GPIO5), A2.7 (GPIO5), J5.10 (GPIO15/RXD)
unnamed: A1.9 (GPIO6), A2.9 (GPIO6), J5.16 (GPIO23)
unnamed: A1.10 (GPIO7), A2.10 (GPIO7), J5.12 (GPIO18/PWM0)
unnamed: A1.11 (GPIO8), A2.11 (GPIO8), J5.35 (GPIO19/POCI1)
unnamed: A1.12 (GPIO9), A2.12 (GPIO9), J5.22 (GPIO25)
unnamed: A1.14 (GPIO10), A2.14 (GPIO10), J5.26 (~CE1/GPIO7)
unnamed: A1.15 (GPIO11), A2.15 (GPIO11), J5.18 (GPIO24)
unnamed: A1.16 (GPIO12), A2.16 (GPIO12), J5.32 (PWM0/GPIO12)
unnamed: A1.17 (GPIO13), A2.17 (GPIO13), J5.36 (GPIO16)
unnamed: A1.19 (GPIO14), A2.19 (GPIO14), J5.40 (GPIO21/SCLK1)
unnamed: A1.20 (GPIO15), A2.20 (GPIO15), J5.38 (GPIO20/PICO1)
unnamed: A1.21 (GPIO16), A2.21 (GPIO16), J5.21 (POCI0/GPIO9)
unnamed: A1.22 (GPIO17), A2.22 (GPIO17), J5.24 (~CE0/GPIO8)
unnamed: A1.24 (GPIO18), A2.24 (GPIO18), J5.23 (SCLK0/GPIO11)
unnamed: A1.25 (GPIO19), A2.25 (GPIO19), J5.19 (PICO0/GPIO10)
unnamed: A1.26 (GPIO20), A2.26 (GPIO20), J5.15 (GPIO22), R13.1
unnamed: A1.27 (GPIO21), A2.27 (GPIO21), J5.13 (GPIO27), J10.3, J11.3
unnamed: A1.29 (GPIO22), A2.29 (GPIO22), J5.11 (GPIO17), J9.3, J12.3
unnamed: A1.32 (GPIO27_ADC1), A2.32 (GPIO27_ADC1), J5.37 (GPIO26)
unnamed: A1.34 (GPIO28_ADC2), A2.34 (GPIO28_ADC2), J5.7 (GCLK0/GPIO4)
unnamed: A1.30 (RUN), A2.30 (RUN)
unnamed: A1.40 (VBUS), A2.40 (VBUS)
unnamed: C7.2, J1.1, J1.3, R3.1
unnamed: J1.2, R6.2 (Wiper), R7.1
unnamed: J1.4, R6.1
unnamed: J2.2, R3.2 (Wiper)
unnamed: J6.2, R12.2
unnamed: J6.3, R13.2
OUTPUTB_ADC: A1.31 (GPIO26_ADC0), A2.31 (GPIO26_ADC0), J5.33 (PWM1/GPIO13), R5.1, R7.2

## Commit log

2025-06-02 Added p2.54mm dupont headers as alternative for Stemma JST connectors
    [TWUSDiySynthKit.kicad_pcb, TWUSDiySynthKit.kicad_sch]
2025-06-02 Added further guarding traces to reduce EMI, optimised vias etc. etc.
    [TWUSDiySynthKit-B_Cu.gbr, TWUSDiySynthKit-B_Mask.gbr, TWUSDiySynthKit-B_Paste.gbr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]
2025-06-02 Labelled test pads
    [TWUSDiySynthKit.kicad_pcb]
2025-06-05 Export using correct tool
    [TWUSDiySynthKit-B_Cu.gbr, TWUSDiySynthKit-B_Mask.gbr, TWUSDiySynthKit-B_Paste.gbr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]
2025-06-05 Improve ground stitching
    [TWUSDiySynthKit.kicad_pcb]
2025-06-05 Added bill of materials
    [ExtraBOM.xlsx, TWUSDiySynthKit.kicad_pcb, TWUSDiySynthKit.kicad_sch]
2025-06-05 Added stuff
    [ExtraBOM.xlsx]
2025-06-05 Added PDF file of pcb and schematic
    [ExtraBOM.xlsx, TWUSDiySynthKit.kicad_pcb, TWUSDiySynthKit.kicad_sch]
2025-06-05 Added images, interactive BOM, journal etc.
2025-06-05 Added logo
    [TWUSDiySynthKit.kicad_pcb]
2025-06-06 more images
    [InitialBaseBoard Base.step, InitialBaseBoard Base.stl, InitialBaseBoard Lid.step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]
2025-06-06 Updated BOM to account for quantity, added 3D renders and stuff
    [ExtraBOM.xlsx]
2025-06-06 Added latest cad files
    [InitialBaseBoard Base.step, InitialBaseBoard Lid.step, InitialBaseBoard Lid.stl]
2025-06-06 Added latest cad models with threading and update readme
2025-06-06 Replaced images with ray traced with latest silkscreening
2025-06-06 Added speaker aperture
    [InitialBaseBoard Base.step, InitialBaseBoard Lid.step, InitialBaseBoard Lid.stl]
2025-06-11 widened gnd traces and connected missing gpio trace
    [TWUSDiySynthKit.kicad_pcb]
2025-06-14 Amend lid mounting screw placement
    [InitialBaseBoard v63 Base.stl, InitialBaseBoard v63 Lid.stl]
